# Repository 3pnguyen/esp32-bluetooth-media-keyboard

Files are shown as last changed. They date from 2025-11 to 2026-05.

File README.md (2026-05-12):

# esp32-bluetooth-media-keyboard 

## Electronic project that provides the same control as wireless earbuds.

     

<div align="center">
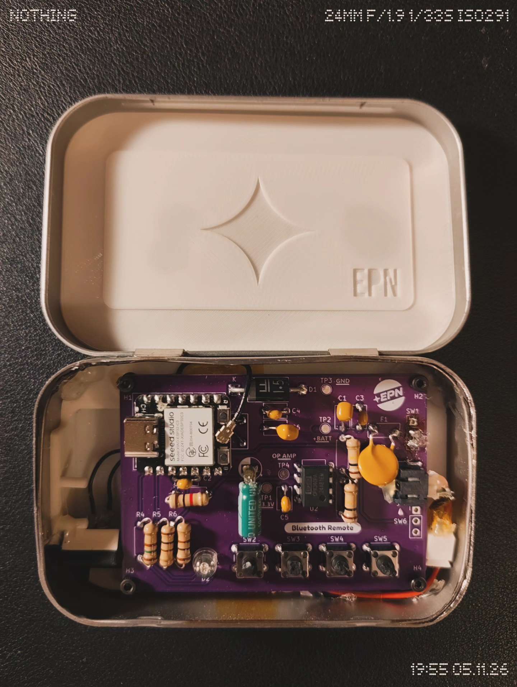
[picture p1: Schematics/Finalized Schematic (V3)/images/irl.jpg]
  
</div>

## ✨ About

This is a repostiory for an electroincs project designed to fit in an Altoids tin with wireless capability to control music playback via Bluetooth. Featuring a 400mAh battery, the circuit also includes a voltage divider + voltage follower setup to reliably measure the battery level & a micro limit switch to trigger sleeping when not in use. The user interface is equiped with 4 push buttons + a compact RGB LED.

When I created the initial prototype (and didn't finish the project), I was not as developed in my electronics skill. Due to being picked up for [Lionstride's Inventeam](https://github.com/3pnguyen/lionstride-inventeam-2026), the project would go under a 6 month hiatus. Drawing closer to the end of the school year, I realized that I could revive the project better than ever. By 6 months, I leveled up my schematic design game, learned to design PCBs, and use programming tools such as PlatformIO. I decided to redesign nearly the entire thing:

<div align="center">
    <table>
        <tr>
            <td> <p> Before: </p> </td>
            <td> <p> After: </p> </td>
        </tr>
        <tr>
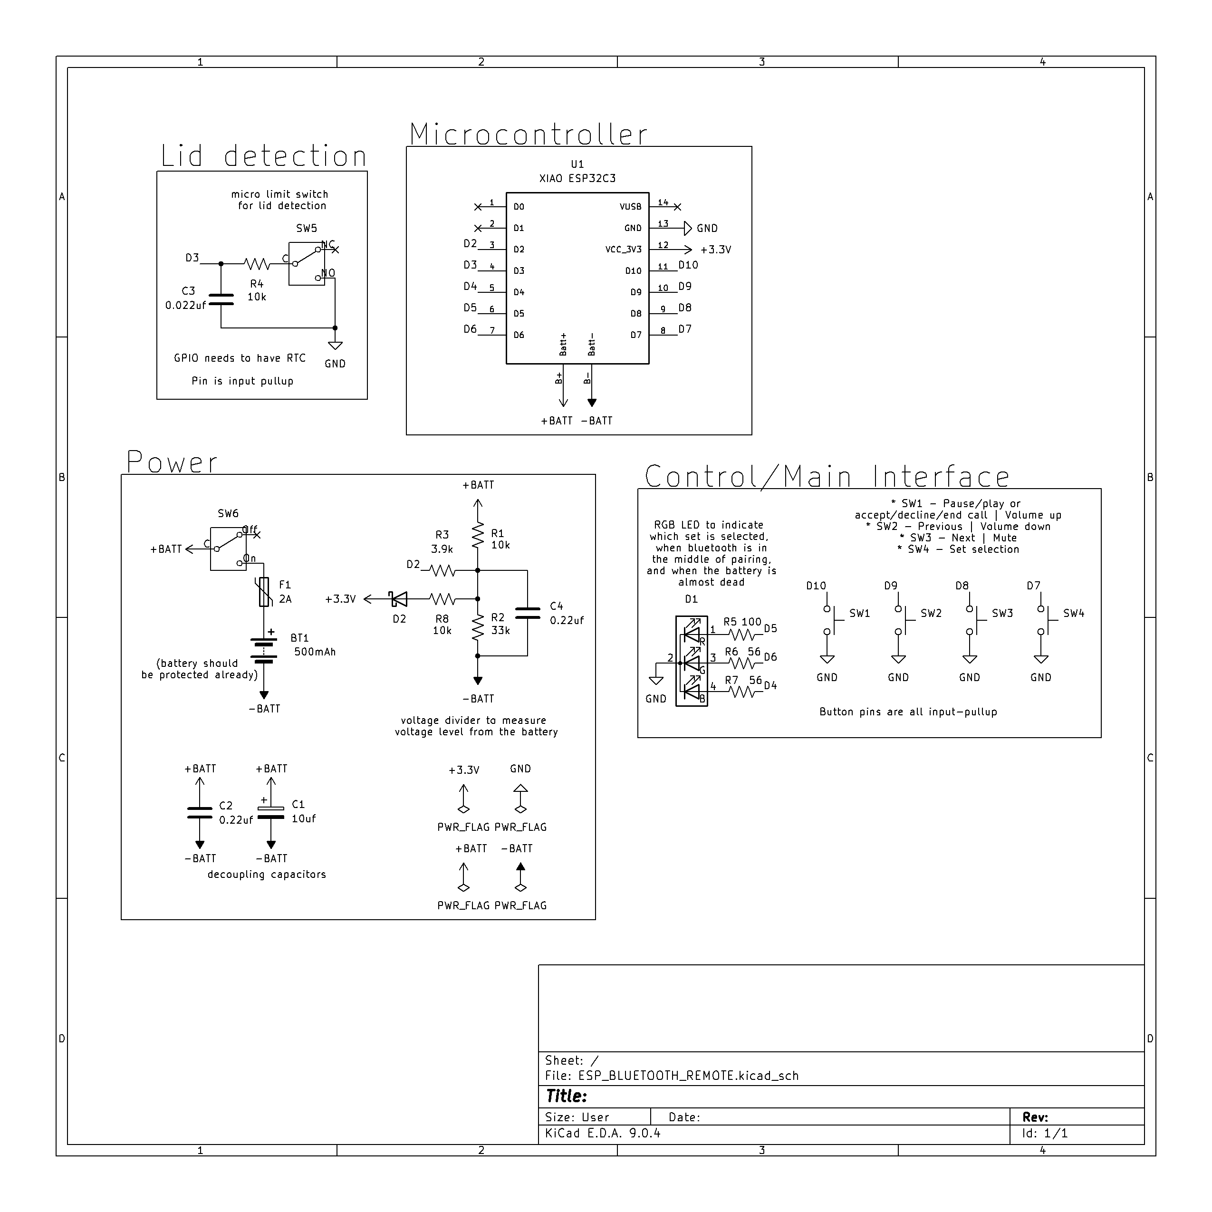
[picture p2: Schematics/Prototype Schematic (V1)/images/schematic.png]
            <td>  </td>
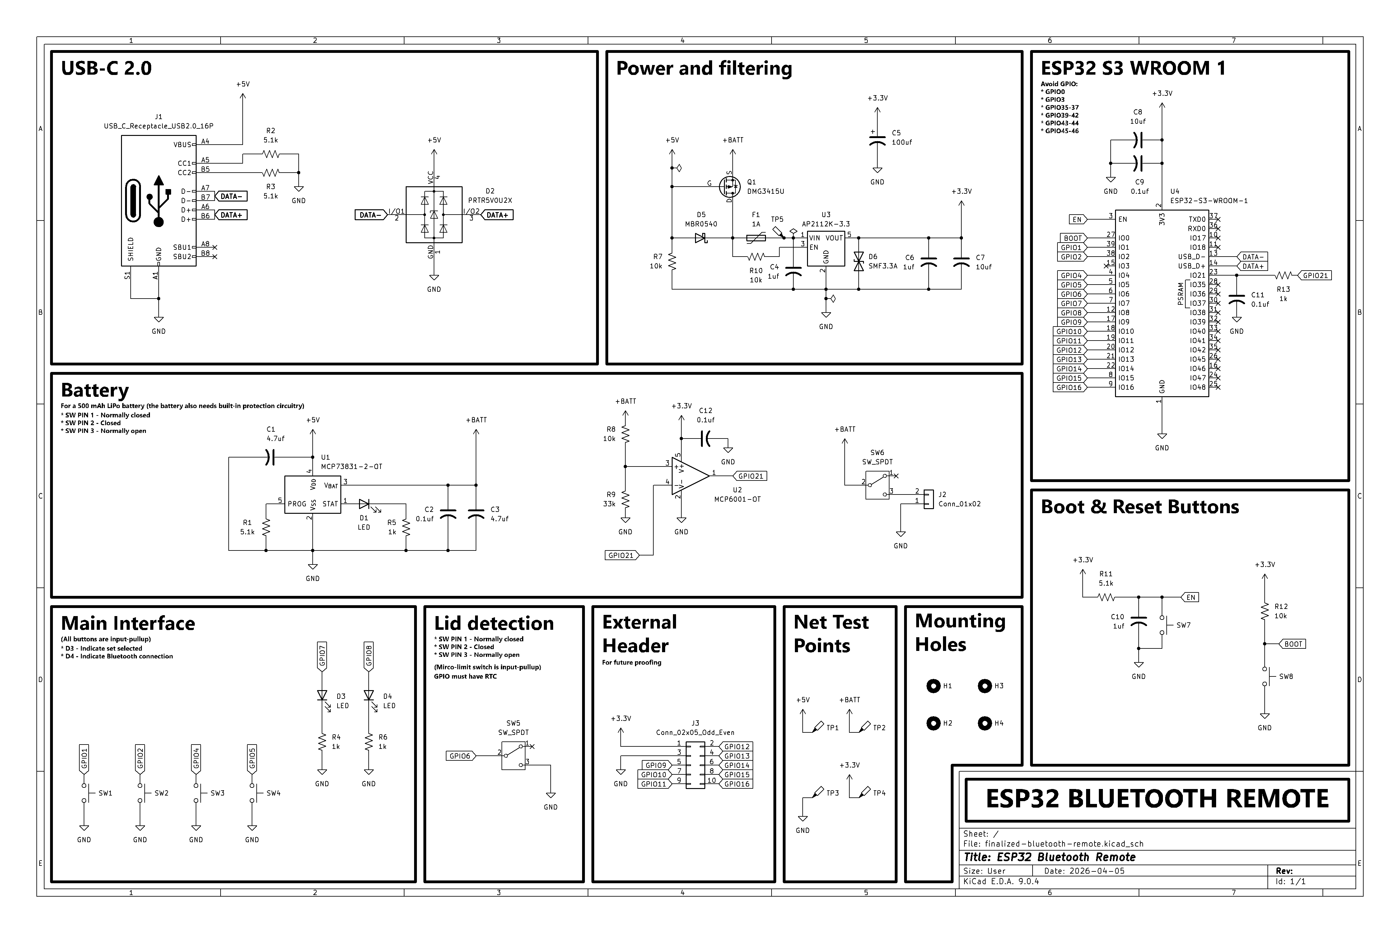
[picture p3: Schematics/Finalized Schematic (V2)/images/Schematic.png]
            <td>  </td>
        </tr>
    </table>
</div>

V2 was a big leap from the initial prototype. But it never ended up being created because it was too expensive. So I went with a hybrid version, V3:

<div align="center">
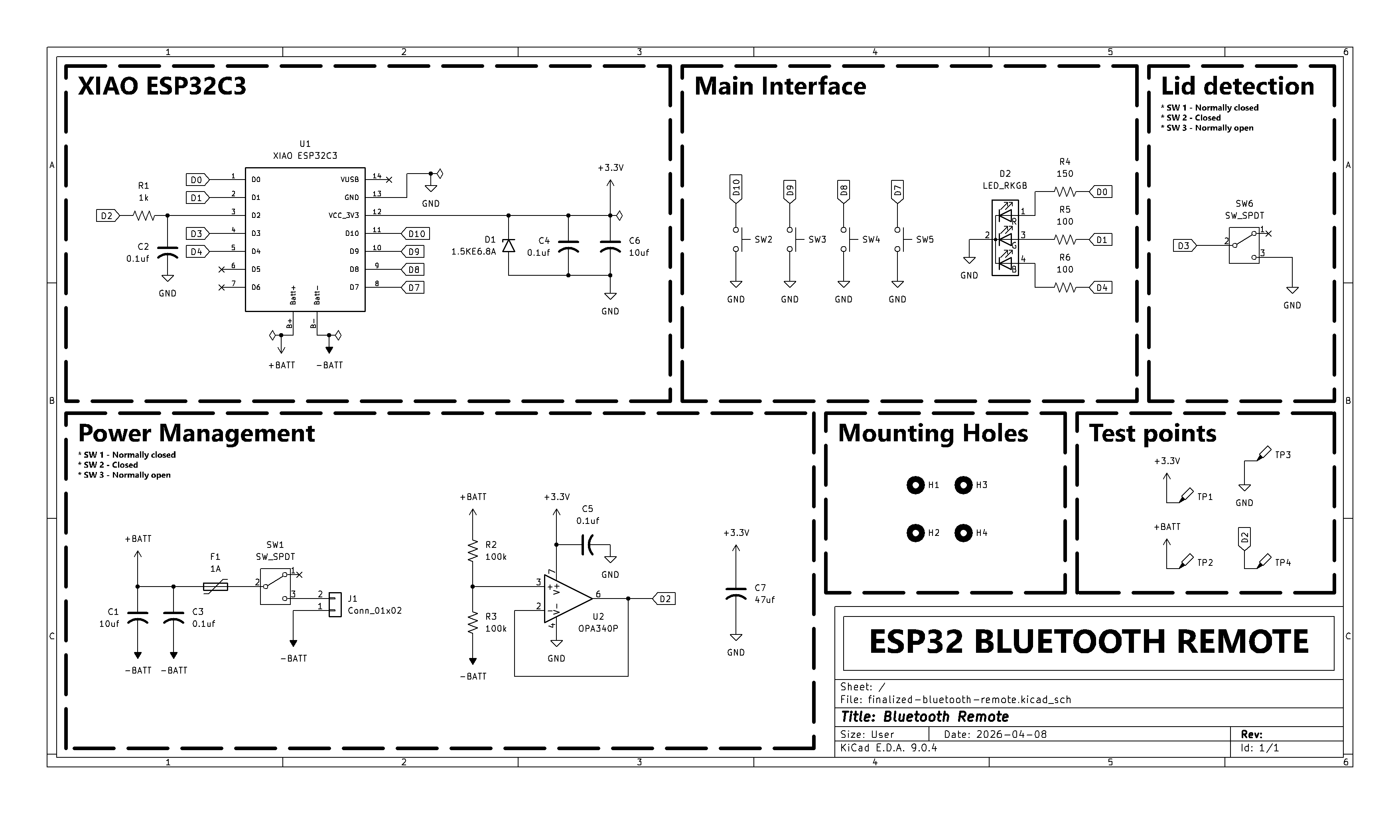
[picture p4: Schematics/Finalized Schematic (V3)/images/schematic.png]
  
</div>

V3 took the pros out of the prototype and V2 - it made the perfect balance of cost and complexity.

It was perfect that the project dragged out the way it did, because I ended up making it better than ever. Other than that, this project has become the benchmark for all of the progress I made in my first year of high school. Other than the project's repository, this is a time capsule for how far I've come - and I'll never forget that.

## 📐 CAD

[Amazing CAD here](https://cad.onshape.com/documents/83f792e68010cb24d3ada2b4/w/ca8c8df538ed234a2d133709/e/c846efb1a51148007d1a6c65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)

<div align="center">
    <table>
        <tr>
            <td> <p> Prototype: </p> </td>
            <td> <p> V3: </p> </td>
        </tr>
        <tr>
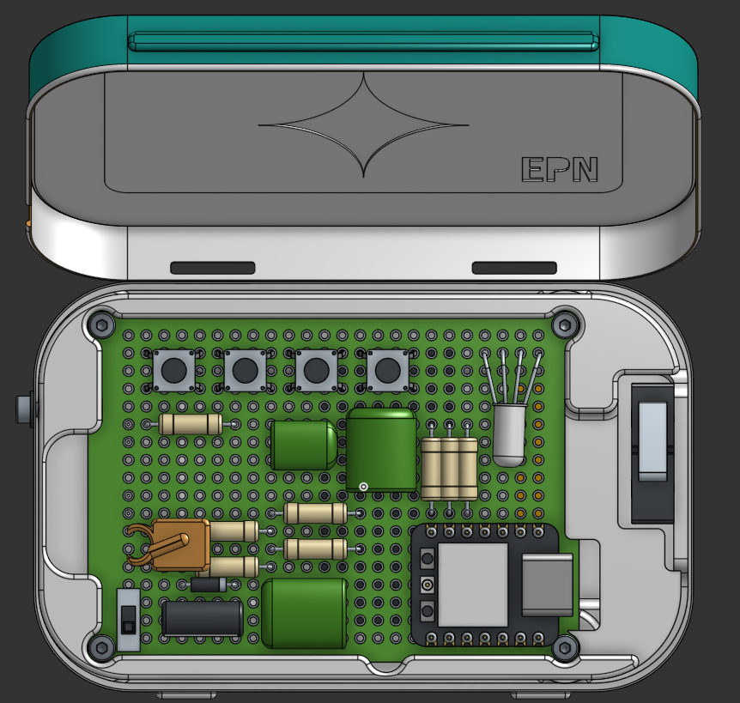
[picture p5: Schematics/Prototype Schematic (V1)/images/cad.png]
            <td>  </td>
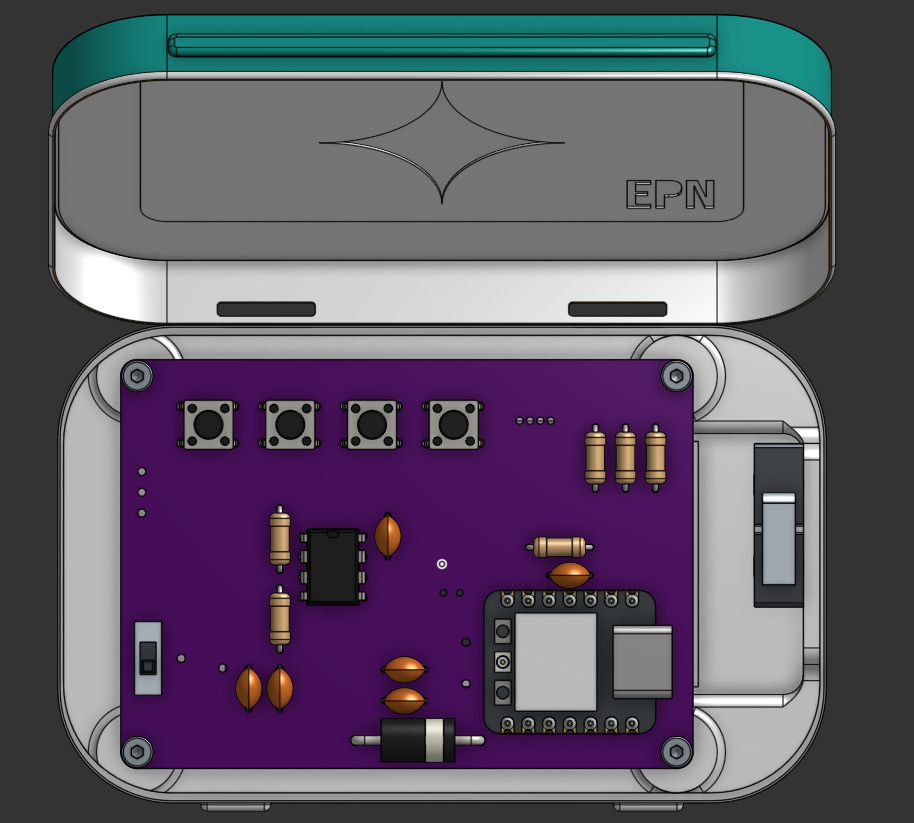
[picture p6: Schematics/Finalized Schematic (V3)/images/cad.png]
            <td>  </td>
        </tr>
    </table>
</div>

I was too lazy to finish the CAD for V3   <3

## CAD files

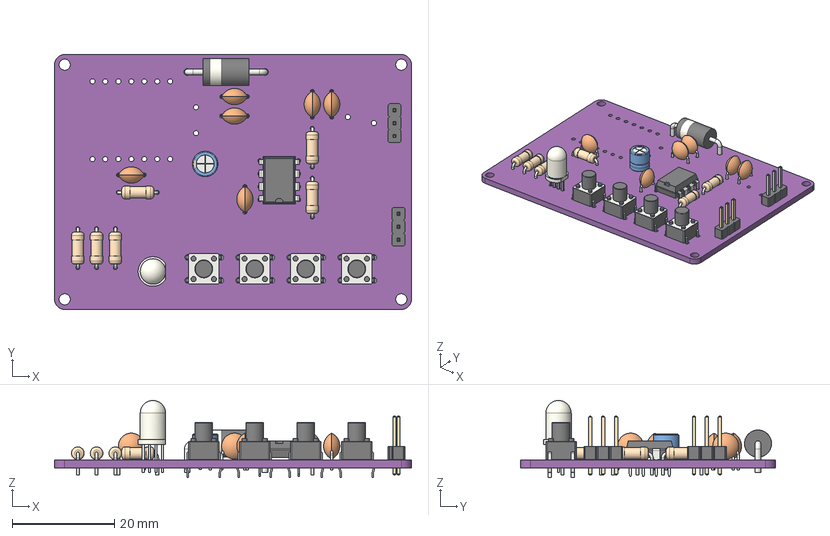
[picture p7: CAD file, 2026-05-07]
Schematics/Finalized Schematic (V3)/finalized-bluetooth-remote/finalized-bluetooth-remote.step
70.0 x 50.0 x 15.1 mm
D_DO-201AE_P15.24mm_Horizontal
SW_PUSH_6mm_H7.3mm x 4
R_Axial_DIN0207_L6.3mm_D2.5mm_P7.62mm_Horizontal x 6
C_Disc_D5.1mm_W3.2mm_P5.00mm x 6
PinHeader_1x03_P2.54mm_Vertical x 2
CP_Radial_D5.0mm_P2.00mm
DIP-8_W7.62mm
LED_D5.0mm-4_RGB
finalized-bluetooth-remote_PCB

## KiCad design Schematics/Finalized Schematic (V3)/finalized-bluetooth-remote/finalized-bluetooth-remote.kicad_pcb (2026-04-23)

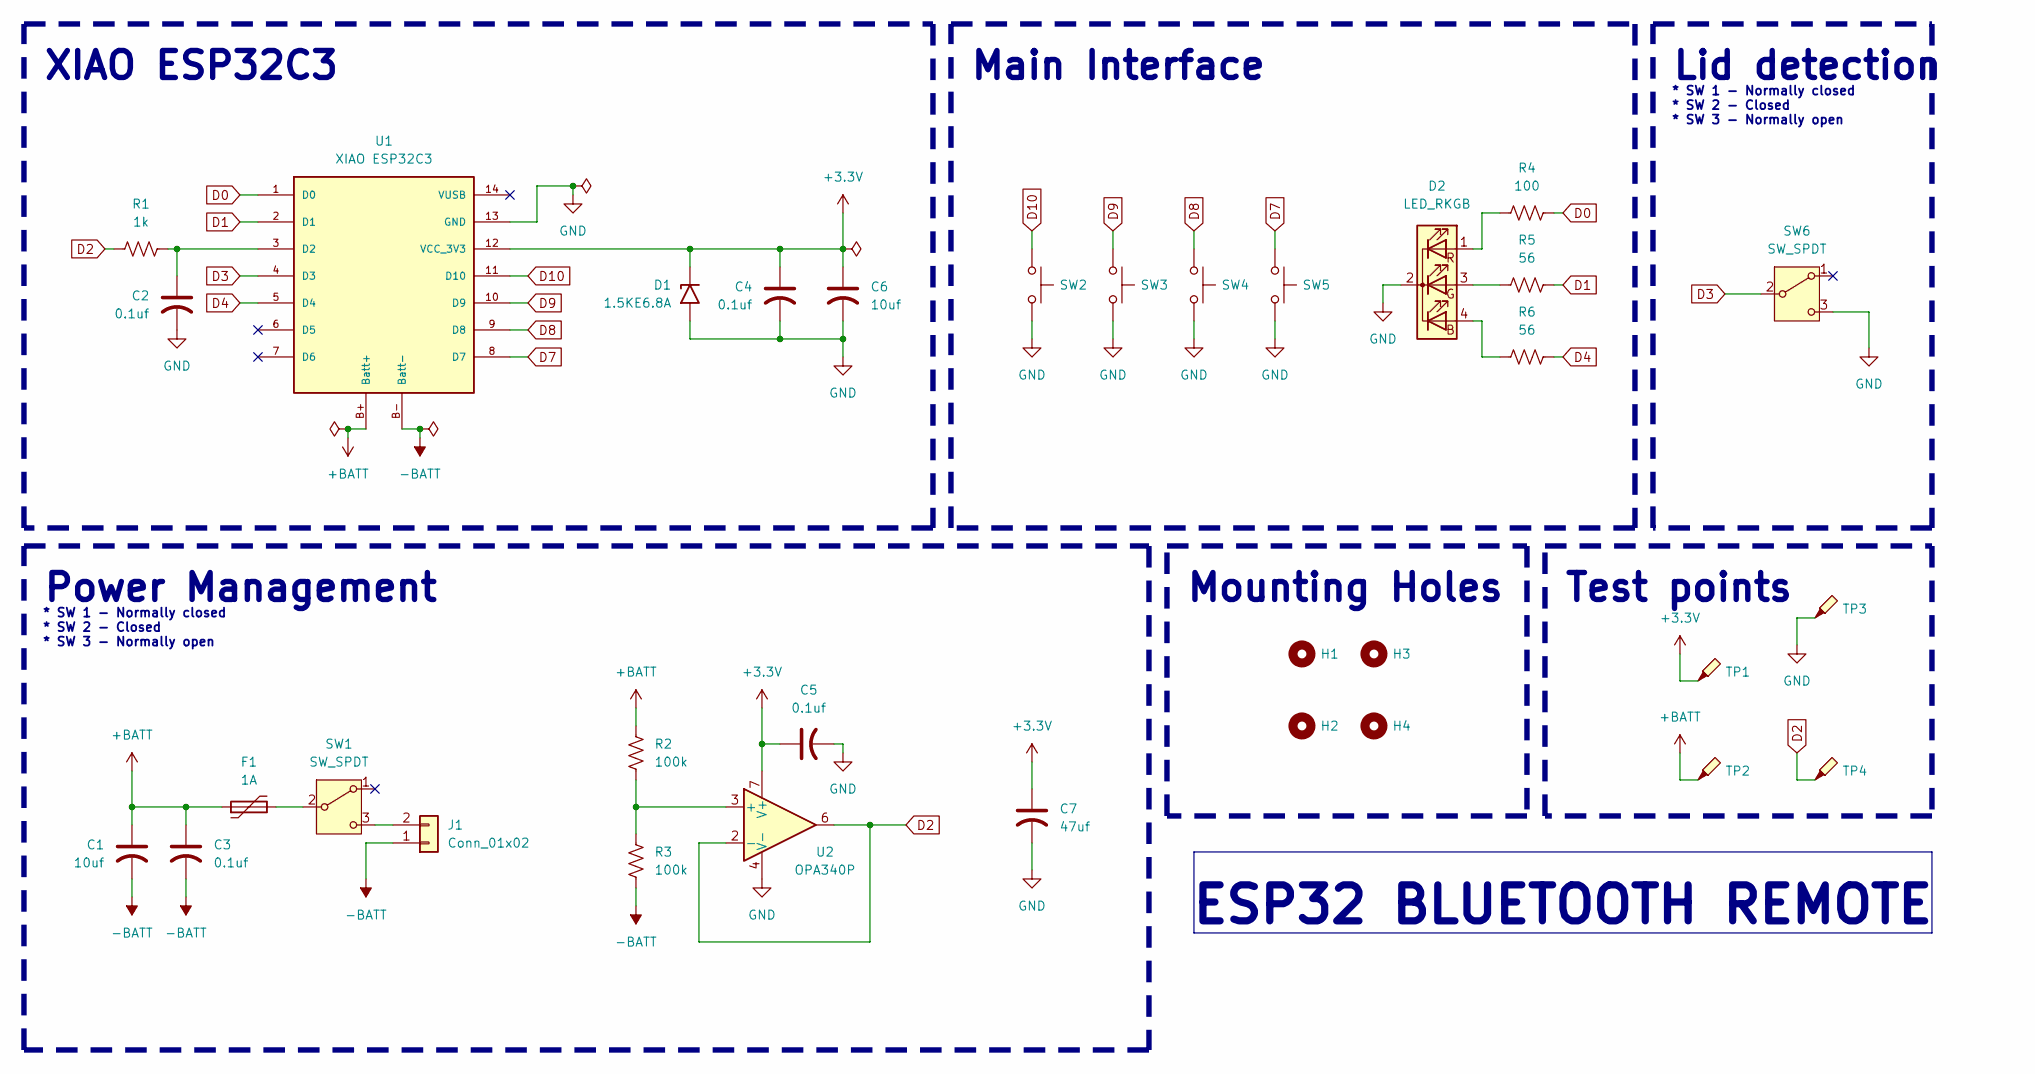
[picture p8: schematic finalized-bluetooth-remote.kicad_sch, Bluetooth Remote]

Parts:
C1, C6: 10uf; C_Disc_D5.1mm_W3.2mm_P5.00mm
C2, C3, C4, C5: 0.1uf; C_Disc_D5.1mm_W3.2mm_P5.00mm
C7: 47uf; CP_Radial_D5.0mm_P2.00mm
D1: 1.5KE6.8A; D_DO-201AE_P15.24mm_Horizontal
D2: LED_RKGB; LED_D5.0mm-4_RGB
F1: 1A; Fuse_Bourns_MF-RG300
H1, H2, H3, H4: MountingHole; MountingHole_2.2mm_M2
J1: Conn_01x02; JST_PH_S2B-PH-SM4-TB_1x02-1MP_P2.00mm_Horizontal
R1: 1k; R_Axial_DIN0207_L6.3mm_D2.5mm_P7.62mm_Horizontal
R2, R3: 100k; R_Axial_DIN0207_L6.3mm_D2.5mm_P7.62mm_Horizontal
R4: 100; R_Axial_DIN0207_L6.3mm_D2.5mm_P7.62mm_Horizontal
R5, R6: 56; R_Axial_DIN0207_L6.3mm_D2.5mm_P7.62mm_Horizontal
SW1, SW6: SW_SPDT; PinHeader_1x03_P2.54mm_Vertical
SW2, SW3, SW4, SW5: SW_Push; SW_PUSH_6mm_H7.3mm
TP1, TP2, TP3, TP4: TestPoint_Probe; TestPoint_Pad_D2.0mm
U1: XIAO ESP32C3; Xiao_esp32c3
U2: OPA340P; DIP-8_W7.62mm

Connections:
+3.3V: C4.1, C5.1, C6.1, C7.1, D1.1 (A1), TP1.1, U1.12 (VCC_3V3), U2.7 (V+)
+BATT: C1.1, C3.1, F1.1, R2.1, TP2.1, U1.B+ (Batt+)
-BATT: C1.2, C3.2, J1.1, R3.2, U1.B- (Batt-)
D0: R4.2, U1.1 (D0)
D1: R5.2, U1.2 (D1)
D2: R1.1, TP4.1, U2.2 (-), U2.6
D3: SW6.2 (B), U1.4 (D3)
D4: R6.2, U1.5 (D4)
D7: SW5.1, U1.8 (D7)
D8: SW4.1, U1.9 (D8)
D9: SW3.1, U1.10 (D9)
D10: SW2.1, U1.11 (D10)
GND: C2.2, C4.2, C5.2, C6.2, C7.2, D1.2 (A2), D2.2 (K), SW2.2, SW3.2, SW4.2, SW5.2, SW6.3 (C), TP3.1, U1.13 (GND), U2.4 (V-)
unnamed: D2.4 (BA), R6.1
unnamed: D2.3 (GA), R5.1
unnamed: D2.1 (RA), R4.1
unnamed: J1.2, SW1.3 (C)
unnamed: F1.2, SW1.2 (B)
unnamed: C2.1, R1.2, U1.3 (D2)
unnamed: R2.2, R3.1, U2.3 (+)

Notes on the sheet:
* SW 1 - Normally closed * SW 2 - Closed * SW 3 - Normally open
Mounting Holes
ESP32 BLUETOOTH REMOTE
Lid detection
Main Interface
Power Management
Test points
XIAO ESP32C3

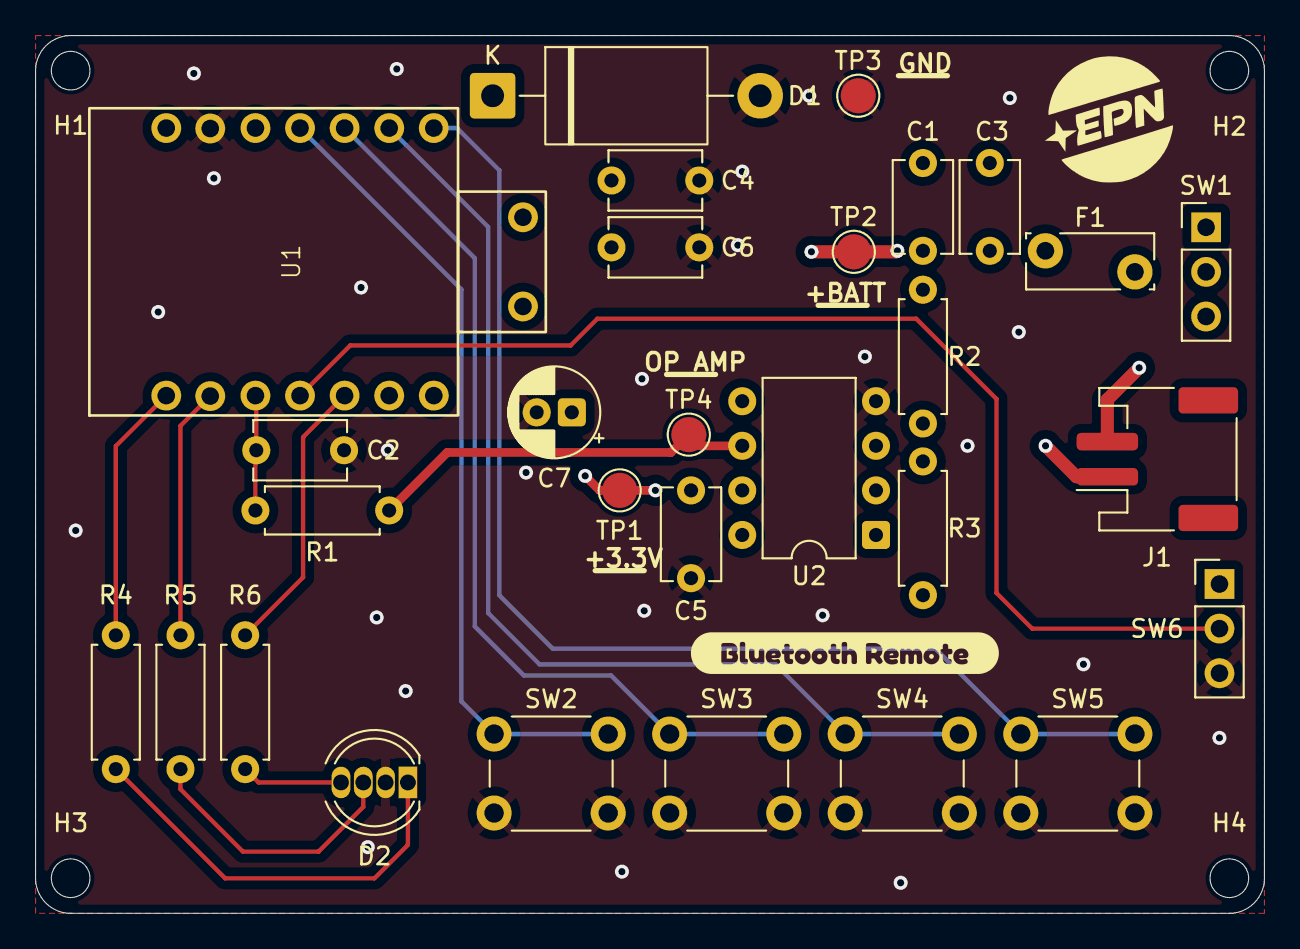
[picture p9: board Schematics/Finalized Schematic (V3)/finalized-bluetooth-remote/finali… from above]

Board: 4 copper layers, 70.0 x 50.0 mm, 34 parts (0 on the bottom side), 20 nets.

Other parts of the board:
kibuzzard-69E979CA: G***; kibuzzard-69E979CA

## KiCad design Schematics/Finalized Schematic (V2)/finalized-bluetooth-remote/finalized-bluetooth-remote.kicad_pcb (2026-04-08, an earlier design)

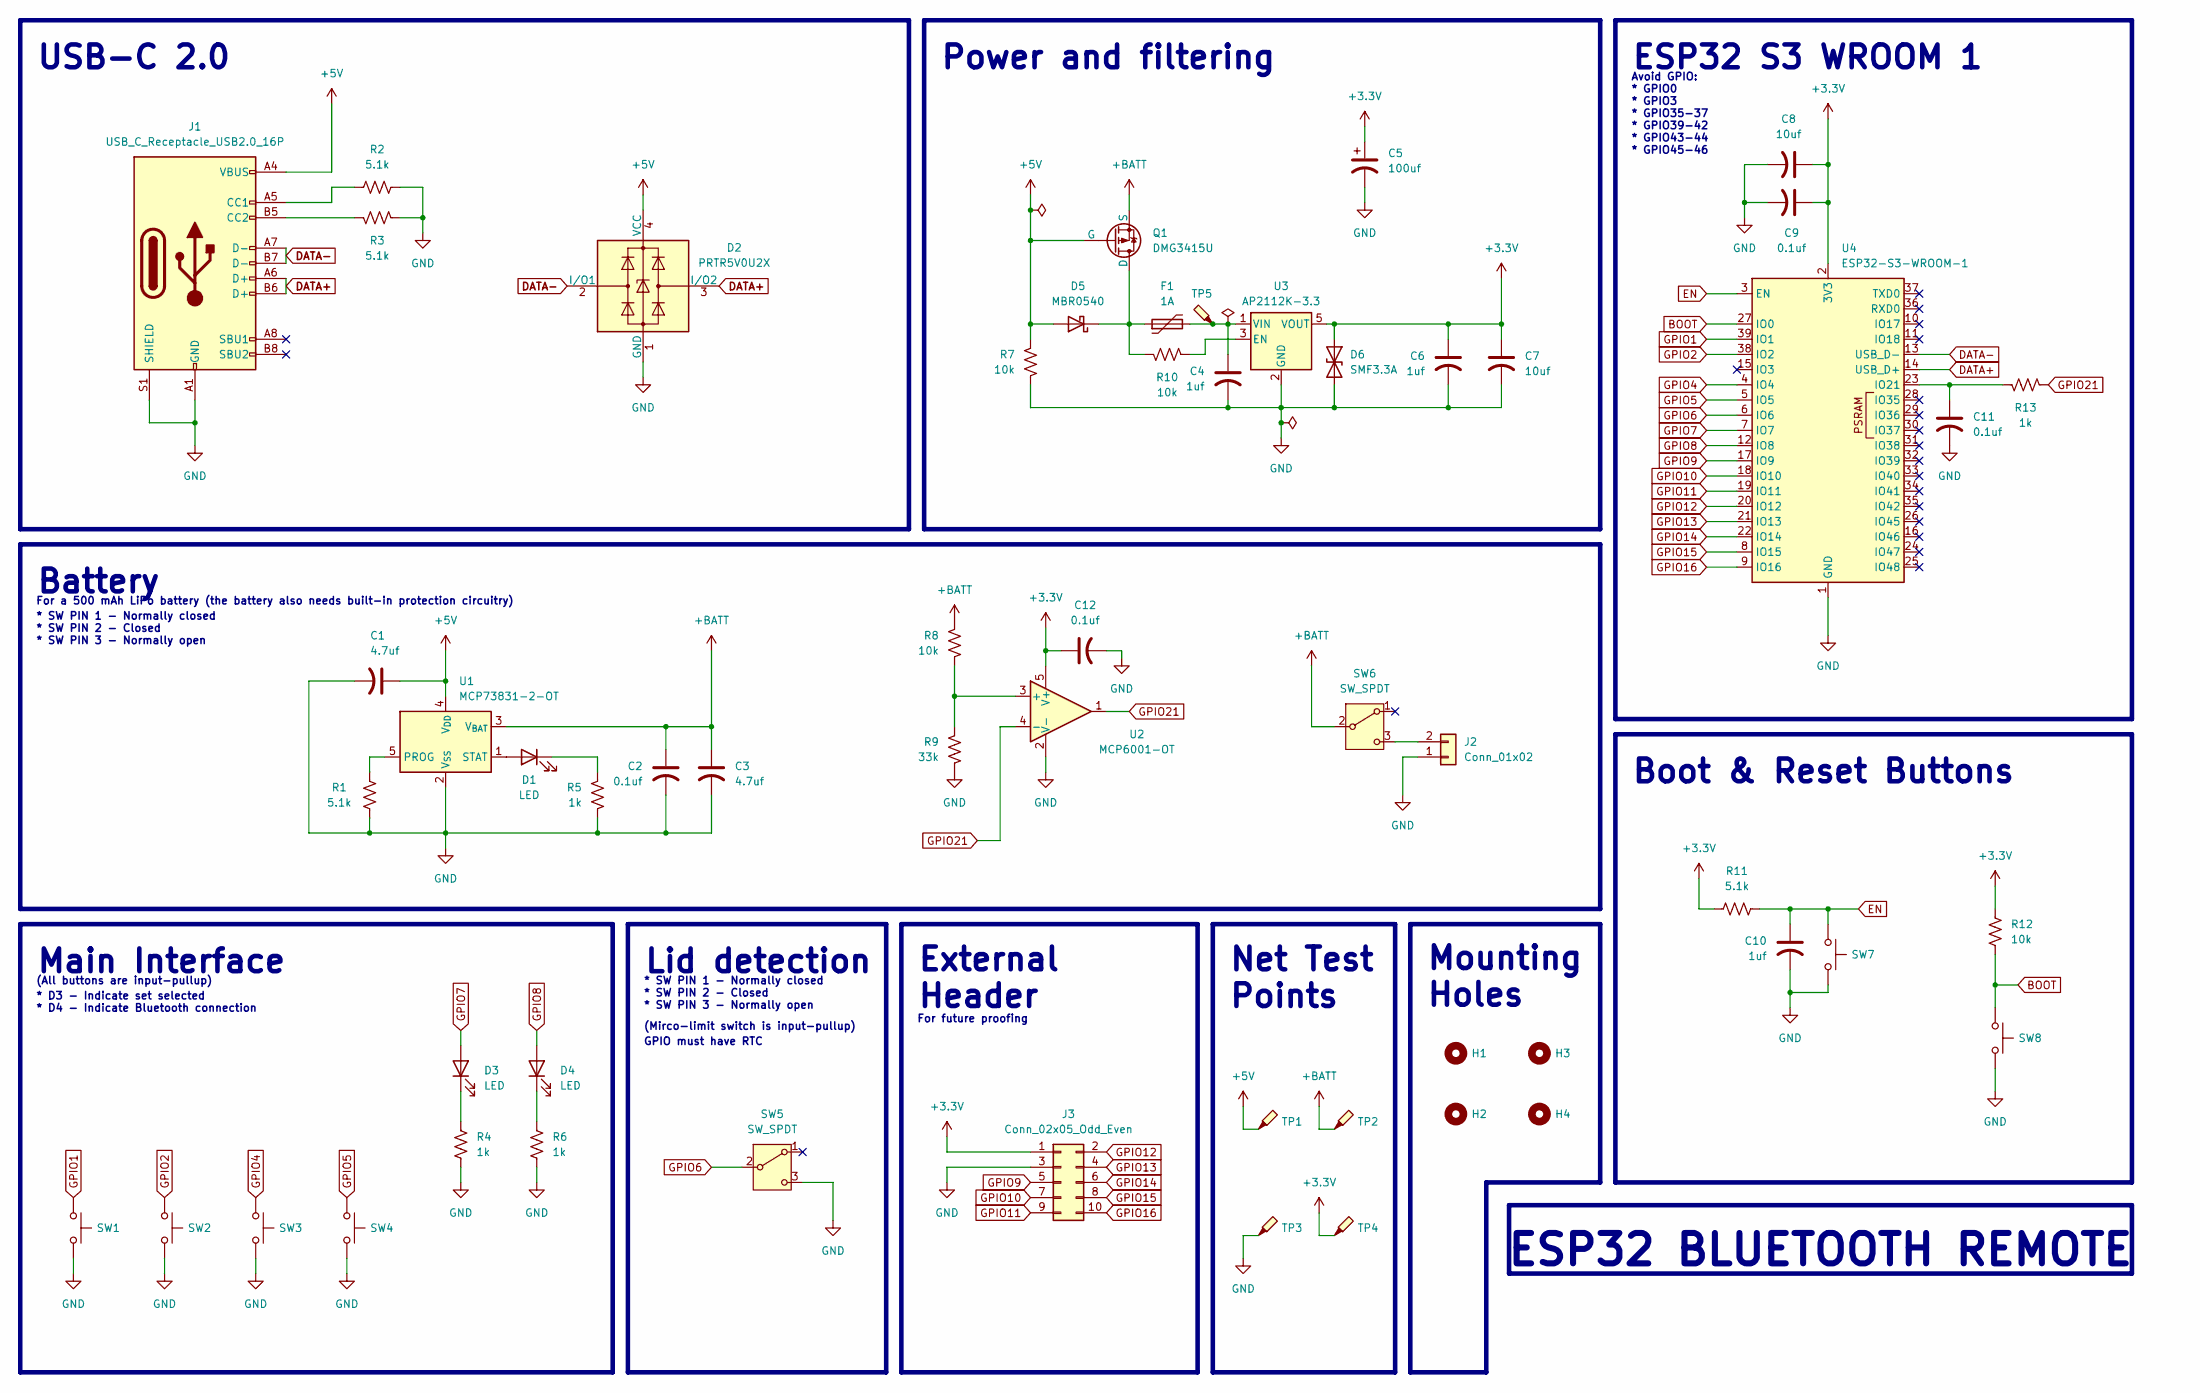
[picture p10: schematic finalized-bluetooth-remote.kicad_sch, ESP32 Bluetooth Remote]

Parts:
C1, C3: 4.7uf; C_0805_2012Metric; LCSC C1746
C2, C9, C11, C12: 0.1uf; C_0603_1608Metric; LCSC C1590
C4, C6, C10: 1uf; C_0603_1608Metric; LCSC C1592
C5: 100uf; CP_EIA-7343-31_Kemet-D; LCSC C90975
C7, C8: 10uf; C_0805_2012Metric; LCSC C1713
D1, D3, D4: LED; LED_0603_1608Metric; LCSC C2288
D2: PRTR5V0U2X; SOT-143; LCSC C2827688
D5: MBR0540; D_SOD-123; LCSC C77337
D6: SMF3.3A; D_SOD-123F; LCSC C283866
F1: 1A; Fuse_1812_4532Metric; LCSC C12558
H1, H2, H3, H4: MountingHole; MountingHole_2.2mm_M2
J1: USB_C_Receptacle_USB2.0_16P; USB_C_Receptacle_HRO_TYPE-C-31-M-12; LCSC C165948
J2: Conn_01x02; JST_PH_S2B-PH-SM4-TB_1x02-1MP_P2.00mm_Horizontal; LCSC C295747
J3: Conn_02x05_Odd_Even; PinHeader_2x05_P2.54mm_Vertical
Q1: DMG3415U; SOT-23; LCSC C7202986
R1, R2, R3, R11: 5.1k; R_0603_1608Metric; LCSC C177348
R4, R5, R6, R13: 1k; R_0603_1608Metric; LCSC C177343
R7, R8, R10, R12: 10k; R_0603_1608Metric; LCSC C177337
R9: 33k; R_0603_1608Metric; LCSC C177291
SW1, SW2, SW3, SW4: SW_Push; SW_SPST_Omron_B3FS-100xP; LCSC C87038
SW5, SW6: SW_SPDT; PinHeader_1x03_P2.54mm_Vertical
SW7, SW8: SW_Push; SW_Push_1P1T_NO_CK_KMR2; LCSC C72443
TP1, TP2, TP3, TP4, TP5: TestPoint_Probe; TestPoint_Pad_D2.0mm
U1: MCP73831-2-OT; SOT-23-5; LCSC C14879
U2: MCP6001-OT; SOT-23-5; LCSC C21403
U3: AP2112K-3.3; SOT-23-5; LCSC C22365427
U4: ESP32-S3-WROOM-1; LCSC C2913199

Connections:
+3.3V: C5.1, C6.1, C7.1, C8.1, C9.1, C12.1, D6.1 (A1), J3.1, R11.1, R12.1, TP4.1, U2.5 (V+), U3.5 (VOUT), U4.2 (3V3)
+5V: C1.1, D2.4 (VCC), D5.2 (A), J1.A4 (VBUS), J1.A9 (VBUS), J1.B4 (VBUS), J1.B9 (VBUS), Q1.2 (G), R7.2, TP1.1, U1.4 (V_{DD})
+BATT: C2.1, C3.1, Q1.3 (S), R8.1, SW6.2 (B), TP2.1, U1.3 (V_{BAT})
BOOT: R12.2, SW8.1, U4.27 (IO0)
DATA+: D2.3 (I/O2), J1.A6 (D+), J1.B6 (D+), U4.14 (USB_D+)
DATA-: D2.2 (I/O1), J1.A7 (D-), J1.B7 (D-), U4.13 (USB_D-)
EN: C10.1, R11.2, SW7.1, U4.3 (EN)
GND: C1.2, C2.2, C3.2, C4.2, C5.2, C6.2, C7.2, C8.2, C9.2, C10.2, C11.2, C12.2, D2.1 (GND), D6.2 (A2), J1.A1 (GND), J1.A12 (GND), J1.B1 (GND), J1.B12 (GND), J1.S1 (SHIELD), J2.1, J3.3, R1.2, R2.2, R3.2, R4.2, R5.2, R6.2, R7.1, R9.2, SW1.2, SW2.2, SW3.2, SW4.2, SW5.3 (C), SW7.2, SW8.2, TP3.1, U1.2 (V_{SS}), U2.2 (V-), U3.2 (GND), U4.1 (GND), U4.40 (GND), U4.41 (GND)
GPIO1: SW1.1, U4.39 (IO1)
GPIO2: SW2.1, U4.38 (IO2)
GPIO4: SW3.1, U4.4 (IO4)
GPIO5: SW4.1, U4.5 (IO5)
GPIO6: SW5.2 (B), U4.6 (IO6)
GPIO7: D3.2 (A), U4.7 (IO7)
GPIO8: D4.2 (A), U4.12 (IO8)
GPIO9: J3.5, U4.17 (IO9)
GPIO10: J3.7, U4.18 (IO10)
GPIO11: J3.9, U4.19 (IO11)
GPIO12: J3.2, U4.20 (IO12)
GPIO13: J3.4, U4.21 (IO13)
GPIO14: J3.6, U4.22 (IO14)
GPIO15: J3.8, U4.8 (IO15)
GPIO16: J3.10, U4.9 (IO16)
GPIO21: R13.1, U2.1, U2.4 (-)
unnamed: D1.2 (A), U1.1 (STAT)
unnamed: D1.1 (K), R5.1
unnamed: D3.1 (K), R4.1
unnamed: D4.1 (K), R6.1
unnamed: D5.1 (K), F1.1, Q1.1 (D), R10.1
unnamed: J1.A5 (CC1), R2.1
unnamed: J1.B5 (CC2), R3.1
unnamed: J2.2, SW6.3 (C)
unnamed: R1.1, U1.5 (PROG)
unnamed: R8.2, R9.1, U2.3 (+)
unnamed: R10.2, U3.3 (EN)
unnamed: C4.1, F1.2, TP5.1, U3.1 (VIN)
unnamed: C11.1, R13.2, U4.23 (IO21)

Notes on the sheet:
Net Test Points
For a 500 mAh LiPo battery (the battery also needs built-in protection circuitry)
GPIO must have RTC
ESP32 S3 WROOM 1
Avoid GPIO: * GPIO0 * GPIO3 * GPIO35-37 * GPIO39-42 * GPIO43-44 * GPIO45-46
Main Interface
USB-C 2.0
Power and filtering
Lid detection
Battery
* D3 - Indicate set selected * D4 - Indicate Bluetooth connection
External Header
* SW PIN 1 - Normally closed * SW PIN 2 - Closed * SW PIN 3 - Normally open
Boot & Reset Buttons
ESP32 BLUETOOTH REMOTE
Mounting Holes
For future proofing
(Mirco-limit switch is input-pullup)
(All buttons are input-pullup)

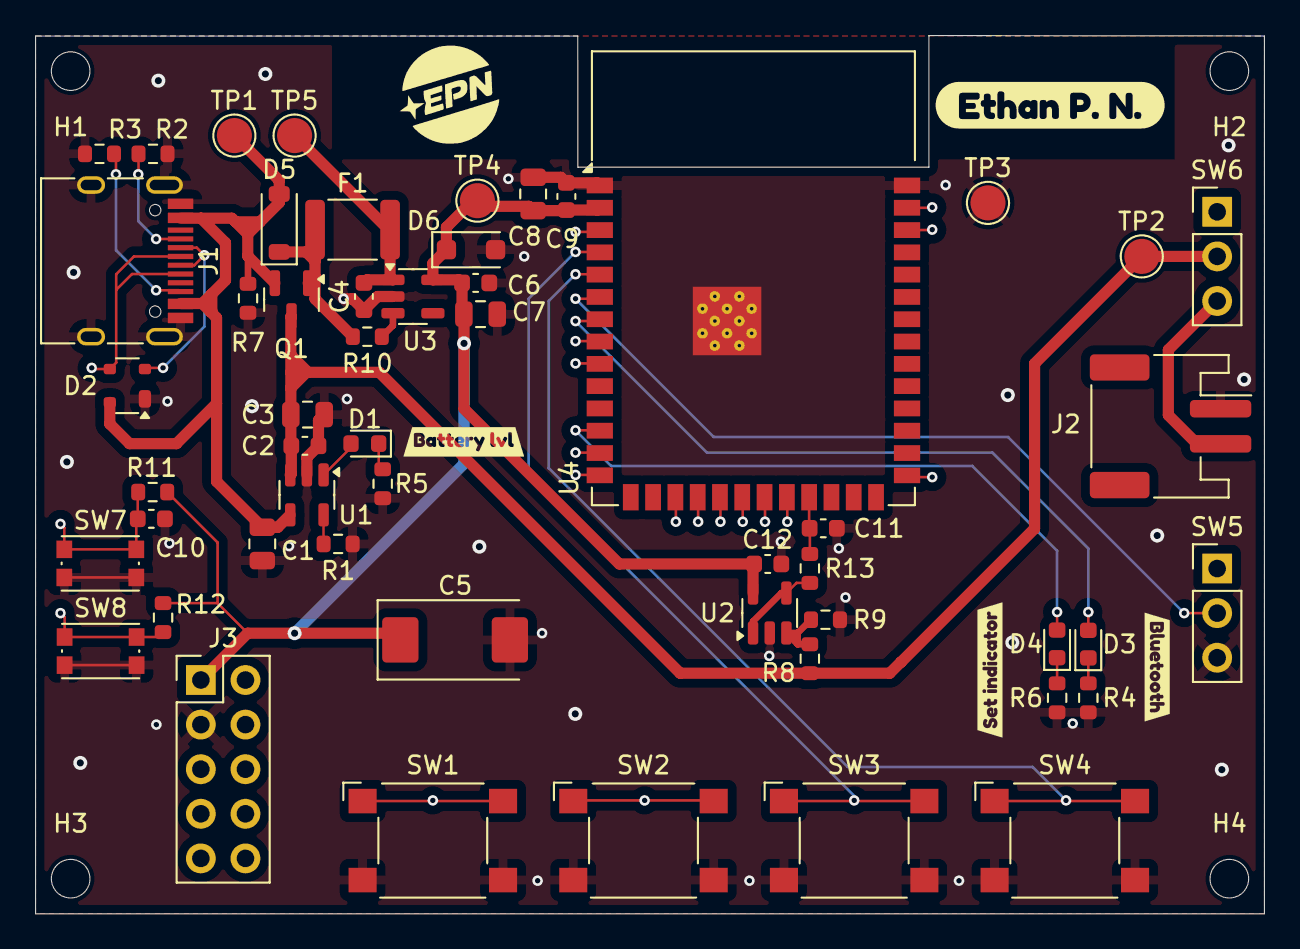
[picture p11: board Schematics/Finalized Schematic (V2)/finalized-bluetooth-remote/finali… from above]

Board: 4 copper layers, 70.0 x 50.0 mm, 61 parts (0 on the bottom side), 37 nets.

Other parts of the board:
kibuzzard-69D59D66: G***; kibuzzard-69D59D66
kibuzzard-69D59D85: G***; kibuzzard-69D59D85
kibuzzard-69D59DAB: G***; kibuzzard-69D59DAB
kibuzzard-69D59DBA: G***; kibuzzard-69D59DBA

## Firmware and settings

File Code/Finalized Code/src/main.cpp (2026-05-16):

#include <Arduino.h>
#include <BleCombo.h>
#include <driver/gpio.h>
#include <esp_sleep.h>
#include "constants/battery.h"
#include "constants/pins.h"
#include "constants/led.h"
#include "functions.h"

#include "classes/ReleaseDebounce.h"
#include "classes/IntervalTimer.h"
#include "classes/Incremental.h"
#include "classes/ChangeDetector.h"
#include "classes/EMAFilter.h"

int section = 0;
// Last battery percentage sent over BLE. Starts invalid so the first reading is always reported.
int reportedBatteryPercent = -1;

void setup() {
  pinMode(BUTTON_1, INPUT_PULLUP);
  pinMode(BUTTON_2, INPUT_PULLUP);
  pinMode(BUTTON_3, INPUT_PULLUP);
  pinMode(BUTTON_4, INPUT_PULLUP);
  pinMode(SLEEP_BUTTON, INPUT_PULLUP);
  pinMode(POWER_VD, INPUT);
  pinMode(INDICATOR_LED_R, OUTPUT);
  pinMode(INDICATOR_LED_G, OUTPUT);
  pinMode(INDICATOR_LED_B, OUTPUT);
  setIndicatorLedsOff();

  Serial.begin(115200);
  Serial.println("\nBegin\n");


  delay(20);
  if (digitalRead(SLEEP_BUTTON) == HIGH) {
    Serial.println("Lid is open – staying awake");
    wakeUp();
  } else {
    Serial.println("Lid closed – go back to sleep immediately");
    goToSleep();
    wakeUp();
  }
}

void loop() {
  #ifndef TEST

    float pinVoltage = analogReadMilliVolts(POWER_VD) / 1000.0;
    float voltage = pinVoltage * ((POWER_VD_R1 + POWER_VD_R2) / POWER_VD_R2);
    voltage_ema.calculate(voltage);
    // Use the filtered voltage for percent conversion; raw ADC readings can jitter enough to bounce the BLE level.
    int percent = voltageToPercent(voltage_ema.level);
    
    if (voltage_ema.aboveThreshold()) setIndicatorLedOff(INDICATOR_LED_R);
    else analogWrite(INDICATOR_LED_R, R_BRIGHTNESS);

    if (digitalRead(SLEEP_BUTTON) == LOW) {
      delay(100);
      if (digitalRead(SLEEP_BUTTON) == LOW) {
        goToSleep();
        wakeUp();
      }
    }

    if (Keyboard.isConnected()) {
      setIndicatorLedsOff();

      if (battery_level_update.isReady()) {
        // Only report meaningful changes so the host does not see 1% oscillations around lookup-table boundaries.
        if (reportedBatteryPercent < 0 || abs(percent - reportedBatteryPercent) >= BATTERY_REPORT_HYSTERESIS) {
          reportedBatteryPercent = percent;
          Keyboard.setBatteryLevel(reportedBatteryPercent);
        }
      }
      
      if (cycle_button.update()) {
        section = (section + 1) % 2;
        Serial.println("Section: " + String(section));
        blinkLED(INDICATOR_LED_G, G_BRIGHTNESS, section + 1, INDICATOR_LED_FLASH_INTERVAL);
      }

      switch (section) {
        case 0:
          if (button_one.update()) pressMediaKey(KEY_MEDIA_PLAY_PAUSE, "Play/Pause");
          else if (button_two.update()) pressMediaKey(KEY_MEDIA_PREVIOUS_TRACK, "Previous Track");
          else if (button_three.update()) pressMediaKey(KEY_MEDIA_NEXT_TRACK, "Next Track");
          break;

        case 1:
          if (button_one.update()) pressMediaKey(KEY_MEDIA_VOLUME_UP, "Volume Up");
          else if (button_two.update()) pressMediaKey(KEY_MEDIA_VOLUME_DOWN, "Volume Down");
          else if (button_three.update()) pressMediaKey(KEY_MEDIA_MUTE, "Mute");
          break;
      }

    } else {
      setIndicatorLedOff(INDICATOR_LED_R);
      setIndicatorLedOff(INDICATOR_LED_G);

      blinkLED(INDICATOR_LED_B, B_BRIGHTNESS, 1, BLUETOOTH_LED_FLASH_INTERVAL);      

      if (null_reconnection.isReady()) {
        null_reconnection.reset();
        ESP.restart();
      }
    }

  #else

  #endif

  delay(5);
}

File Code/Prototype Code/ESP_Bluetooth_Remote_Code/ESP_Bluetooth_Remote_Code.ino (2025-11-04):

#include <BleCombo.h>
#include <esp_sleep.h>
#include "customizable-info/pins.h"
#include "misc/functions.h"
#include "custom-classes/TimeDebounce.h"
#include "custom-classes/ReleaseDebounce.h"
#include "custom-classes/IntervalTimer.h"
#include "custom-classes/Incremental.h"
#include "custom-classes/ChangeDetector.h"
#include "customizable-info/battery.h"
#include "custom-classes/EMAFilter.h"

//#define TEST

ReleaseDebounce button_one(BUTTON_1);
ReleaseDebounce button_two(BUTTON_2);
ReleaseDebounce button_three(BUTTON_3);
ReleaseDebounce cycle_button(BUTTON_4);
//no need for a debounce class for the sleep button
IntervalTimer bluetooth_led_flash(300);
IntervalTimer indicator_led_flash(150);
IntervalTimer null_reconnection(3000);
Incremental indicator_led_incremental;
ChangeDetector<int> section_selection(0);
EMAFilter<float> voltage_ema(0.5, 3.65);
IntervalTimer battery_level_update(1000);

int section = 0;

void setup() {
  pinMode(BUTTON_1, INPUT_PULLUP);
  pinMode(BUTTON_2, INPUT_PULLUP);
  pinMode(BUTTON_3, INPUT_PULLUP);
  pinMode(BUTTON_4, INPUT_PULLUP);
  pinMode(SLEEP_BUTTON, INPUT_PULLUP);
  pinMode(POWER_VD, INPUT);
  pinMode(INDICATOR_LED_R, OUTPUT);
  pinMode(INDICATOR_LED_G, OUTPUT);
  pinMode(INDICATOR_LED_B, OUTPUT);

  Serial.begin(115200);
  Serial.println("\nBegin\n");


  delay(20);
  if (digitalRead(SLEEP_BUTTON) == HIGH) {
    Serial.println("Lid is open – staying awake");
    wakeUp();
  } else {
    Serial.println("Lid closed – go back to sleep immediately");
    goToSleep();
  }
}

void loop() {
  float voltage = (analogRead(POWER_VD) / ADC_MAX) * VREF * ((POWER_VD_R1 + POWER_VD_R2) / POWER_VD_R2);
  voltage_ema.calculate(voltage);
  int percent = voltageToPercent(voltage);
  digitalWrite(INDICATOR_LED_R, (voltage_ema.aboveThreshold()) ? LOW : HIGH);

  if (digitalRead(SLEEP_BUTTON) == LOW) {
    delay(100);
    if (digitalRead(SLEEP_BUTTON) == LOW) {
      goToSleep();
      wakeUp();
    }
  }

  if (Keyboard.isConnected()) {
    if (digitalRead(INDICATOR_LED_B) == HIGH) digitalWrite(INDICATOR_LED_B, LOW);

    if (battery_level_update.isReady()) Keyboard.setBatteryLevel(percent);
    
    if (cycle_button.update()) {
      section = (section + 1) % 2;
      Serial.println("Section: " + String(section));
    }

    #ifdef TEST
    #else
      if (section_selection.update(section)) indicator_led_incremental.reset();
      switch (section) {
        case 0:
          if (button_one.update()) pressMediaKey(KEY_MEDIA_PLAY_PAUSE, "Play/Pause");
          else if (button_two.update()) pressMediaKey(KEY_MEDIA_PREVIOUS_TRACK, "Previous Track");
          else if (button_three.update()) pressMediaKey(KEY_MEDIA_NEXT_TRACK, "Next Track");
          if (indicator_led_flash.isReady() && indicator_led_incremental.counter < 2) {
            indicator_led_incremental.increment();
            digitalWrite(INDICATOR_LED_G, (digitalRead(INDICATOR_LED_G) == HIGH) ? LOW : HIGH);
          }
          break;

        case 1:
          if (button_one.update()) pressMediaKey(KEY_MEDIA_VOLUME_UP, "Volume Up");
          else if (button_two.update()) pressMediaKey(KEY_MEDIA_VOLUME_DOWN, "Volume Down");
          else if (button_three.update()) pressMediaKey(KEY_MEDIA_MUTE, "Mute");
          if (indicator_led_flash.isReady() && indicator_led_incremental.counter < 4) {
            indicator_led_incremental.increment();
            digitalWrite(INDICATOR_LED_G, (digitalRead(INDICATOR_LED_G) == HIGH) ? LOW : HIGH);
          }
          break;
      }
    #endif

  } else {
    if (bluetooth_led_flash.isReady()) digitalWrite(INDICATOR_LED_B, (digitalRead(INDICATOR_LED_B) == HIGH) ? LOW : HIGH);
    if (digitalRead(INDICATOR_LED_G) == HIGH) digitalWrite(INDICATOR_LED_G, LOW);
    if (null_reconnection.isReady()) {
      null_reconnection.reset();
      ESP.restart();
    }
  }

  delay(5);
}

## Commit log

2025-11-28 Enhance README with project description and schematic
    Added sections for project details and schematic.
2026-04-06 Reformat repo for improvements
    [ESP_BLUETOOTH_REMOTE.kicad_pcb, ESP_BLUETOOTH_REMOTE.kicad_sch]
2026-04-06 Finished finalized schematic
    [finalized-bluetooth-remote.kicad_pcb, finalized-bluetooth-remote.kicad_sch]
2026-04-08 finished PCB design
    [finalized-bluetooth-remote.kicad_pcb, finalized-bluetooth-remote.kicad_sch]
2026-04-08 finished version of finalized schematic
    [bom.csv, designators.csv, finalized-bluetooth-remote.kicad_pcb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]
2026-04-09 Schematic version 3
    [ESP_BLUETOOTH_REMOTE.kicad_pcb, ESP_BLUETOOTH_REMOTE.kicad_sch, bom.csv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]
2026-04-10 Assigned footprints for PCB
    [finalized-bluetooth-remote.kicad_pcb, finalized-bluetooth-remote.kicad_sch]
2026-04-23 Moved files + finished PCB V3
    [ESP_BLUETOOTH_REMOTE.kicad_pcb, ESP_BLUETOOTH_REMOTE.kicad_sch, bom.csv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]
2026-04-23 Confirm PCB V3
    [finalized-bluetooth-remote.kicad_pcb]
2026-04-23 Rename folders and initialize PlatformIO code
    [ESP_BLUETOOTH_REMOTE.kicad_pcb, ESP_BLUETOOTH_REMOTE.kicad_sch, finalized-bluetooth-remote.kicad_pcb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]
2026-04-23 Fix image source in README for finalized schematic
    Corrected image source path for finalized schematic.
2026-04-25 Fixed LEDs blinking during sleep
    [main.cpp]
2026-05-07 Added step file
    [finalized-bluetooth-remote.step]
2026-05-09 Update resistors for LED
    [finalized-bluetooth-remote.kicad_sch]
2026-05-09 Update pins for schematic V3
2026-05-11 Fixed battery readings
2026-05-15 Dimmed the LEDs + fixed bug with the indicator LED
    [functions.cpp]
2026-05-16 Fixed bugs from previous commit + dimmed LEDs more
    [functions.cpp, main.cpp]
